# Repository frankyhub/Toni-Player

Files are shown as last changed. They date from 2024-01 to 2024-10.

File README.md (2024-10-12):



<div align="center">

|[:skull:ISSUE](https://github.com/frankyhub/Toni-Player/issues?q=is%3Aissue)|[:speech_balloon: Forum /Discussion](https://github.com/frankyhub/Toni-Player/discussions)|[:grey_question:WiKi](https://github.com/frankyhub/Toni-Player/wiki)||
|--|--|--|--|
| | | | |
||<a href="https://github.com/frankyhub/Toni-Player/issues">|<a href="https://github.com/frankyhub/Toni-Player/discussions">|<a href="https://github.com/frankyhub/Toni-Player/releases">|
|| <a href="https://github.com/frankyhub/Toni-Player/pulse" alt="Activity">| <a href="https://github.com/frankyhub/Toni-Player/graphs/traffic">  |<a href="https://github.com/frankyhub?tab=stars"> |
</div>

# Toni-Player

## Story
Dieses Projekt beschreibt einen einfach zu bedienenden MP3-Player für Kinder. Die wesentlichen Komponenten sind ein ESP32, ein RFID-Modul, ein SD-Kartenleser, ein Verstärker und ein Lautsprecher. Optional sind noch ein Akku mit Laderegler und ein Step-Up-Modul möglich. Die Grundidee des ToniPlayers besteht darin, dass Tracks einfach ausgewählt werden, indem ein RFID-getaggtes Objekt auf dem Player platziert wird, wodurch ein physischer Schlüssel zu einer Datei oder einen Ordner erstellt wird.

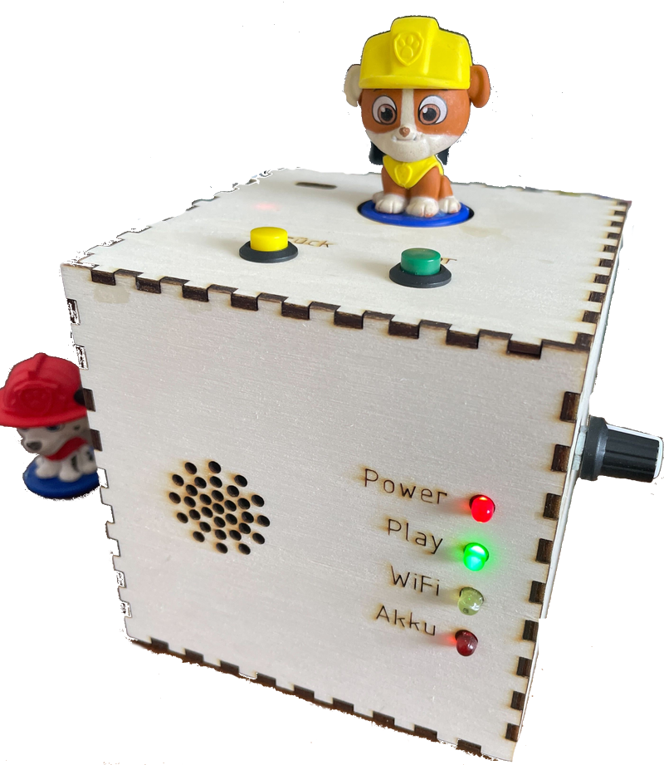
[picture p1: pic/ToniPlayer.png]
Der ToniPlayer


## Grundbedienung
Zunächst muss eine SD-Karte mit MP3-Dateien in Ordnern vorbereitet werden. Die Ordner mit MP3-Dateien können am PC kopiert oder über einen Browser nach Aktivierung des Access Point (AP) auf die SD-Karte geladen werden. Der erste RFID-Tag, der vom Lesegerät gescannt wird, wird zum "Master-Tag". Dieser startet keine Audio-Datei, sondern aktiviert die WiFi-Schnittstelle im AP-Modus, SSID "ToniPlayer", kein Passwort. Die gelbe LED leuchtet. Die nächsten gescannten RIFD-Tags werden automatisch nacheinander mit den Ordnern verknüpft, die MP3-Dateien enthalten. Die Verknüpfung zwischen RFID-Tags und Dateien wird in der Datei "tags.txt" im Stammordner der SD-Karte gespeichert. Wenn die automatische Verknüpfung nicht zu den gewünschten Ergebnissen führt, kannst du diese Datei einfach in einem Texteditor bearbeiten. Um neue Tracks auf den ToniPlayer hochzuladen, scannst du den "Master-Tag", verbindest dich in den Netzwerkeinstellungen des Handys/Tablet mit dem ToniPlayer AP und startest im Browser http://192.168.4.1 . Jetzt kannst du einen Track oder die Verzeichnis auf die SD-Karte laden. Entferne den WIFI-Tag, lege einen neuen, noch nicht zugewiesenen RFID-Tag auf den RFID-Scanner um ihn mit dem neu hochgeladenen Verzeichnis/MP3-Datei zu verknüpfen. Wird ein zugewiesener RFID-Tag auf den Kartenleser gestellt, starten die zugewiesenen MP3-Dateien und die grüne LED leuchtet. Beim Entfernen des RFID-Tag stoppt der ToniPlayer und es blinkt die grüne LED. Nach einer Minute geht der ToniPlayer in den Standby-Betrieb, alle LEDs sind dann aus. Die vor- und zurück-Taste erlauben im Play-Betrieb das skippen der MP3-Dateien. Ein kurzer Tastendruck skippt eine MP3-Datei und ein lager Tastendruck bedeutet schneller Vor- oder Rücklauf. Die Reset-Taste startet den ToniPlayer neu. Leuchtet die rote Akku-LED empfiehlt es sich den Akku zeitnah aufzuladen. Dies ist mit einem USB-Mini Kabel mit einem 5V Handy-Ladegerät oder einer 5V Power-Bank möglich. Sie zeigt auch Fehlerzustände an.

Bearbeiten der SD-Karte am PC
Kopiere deine MP3-Dateien in ein Verzeichnis. Z.B.: 01Album / 01xxx.mp3. Verzeichnisse können beliebig verschachtelt werden, aber jedes Verzeichnis sollte nur MP3-Dateien oder Unterverzeichnisse enthalten. Wenn die automatische Zuordnung von Schlüsseln zu Ordnern nicht korrekt ist, kannst du die "tags.txt" manuell bearbeiten. Du kannst ein Tag auch mit mehreren Verzeichnissen oder beliebigen Dateien verknüpfen. Der Verstärker verfügt über ein Lautstärke-Poti mit Schalter. Ist der Schalter EIN, wird der ToniPlayer mit Spannung versorgt und die POWER-LED leuchtet.

---

## Hardware
Die Hardware für den ToniPlayer:

+ ESP32 Dev Board mit Shield
+ RFID-RC522 Kartenleser
+ SD-Kartenleser (SD-Karte: 32GB 90MB/sec)
+ NF-Verstärker mit Lautsprecher
+ 3,7V Akku 18650 mit Laderegler, Akku-Case (3D-Druck)
+ Step-Up-Modul (3,7V>5V)
+ 4 LEDs, gelb, grün, 2x rot
+ 3 Taster (vor, zurück, Reset)
+ Gehäuse (Lasercutter)
+ Abstandshalter (3D-Druck)
+ Verbrauchs- und Hilfsmaterial

---

## Aufbau und Montage

Verdrahtung:

+ ESP32 > RFID-RC522
+ 3.3V -> 3.3V
+ GPIO4 -> RST
+ GND -> GND
+ N/C -> IRQ
+ GPIO19 -> MISO
+ GPIO23 -> MOSI
+ GPIO18 -> SCK
+ GPIO5 -> SDA

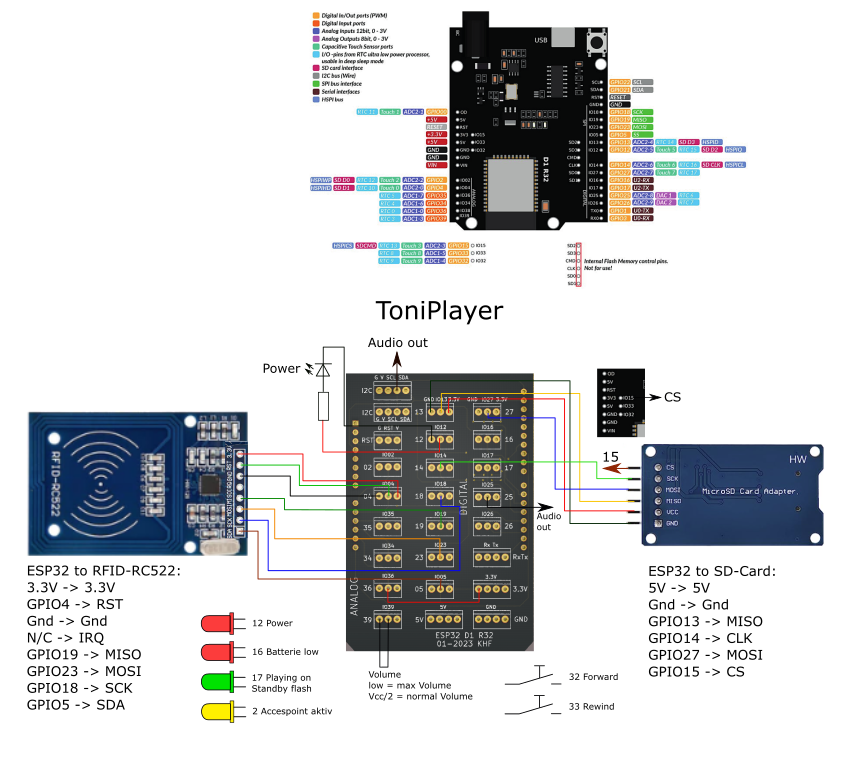
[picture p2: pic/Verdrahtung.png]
Verdrahtung


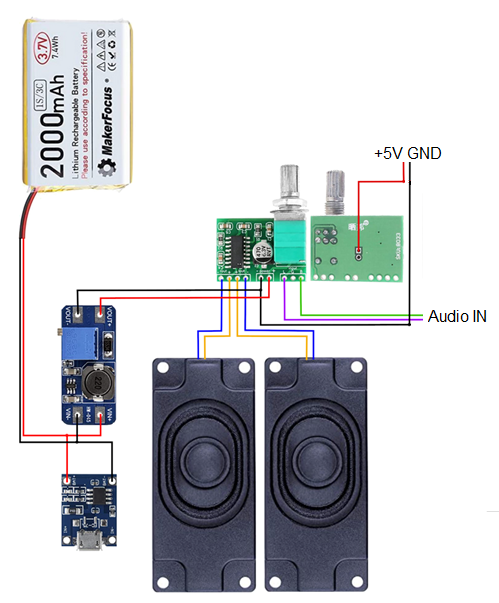
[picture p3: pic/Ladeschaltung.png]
Die Ladeschaltung


---

+ ESP32 > SD-Card
+ 5V -> 5V
+ GND -> GND
+ GPIO13 -> MISO
+ GPIO14 -> CLK
+ GPIO27 -> MOSI
+ GPIO15 -> CS

---

ESP32 > Audio

GPIO22 -> in
GND -> GND
GPIO39 -> Gnd (max volume) oder VCC/2 (normal volume)
GPIO36 -> 3.3V

---

Verstärker mit Lautsprecher

+ ESP32 > Anzeige
+ 4 Status-LEDs (gemeinsame Kathode, 1000Ohm Vorwiderstände):
+ GPIO21 -> Gelb (leuchtet, wenn WIFI aktiviert ist, blinkt bei WIFI-Aktivität)
+ GPIO17 -> Grün (leuchtet während des Spielens, blinkt im Leerlauf)
+ GPIO16 -> Rot (zeigt Fehlerzustände an und Akku laden)
+ GPIO12 -> Rot (zeigt Power an)

---

## Steuerung

Zwei Tasten
GPIO32 und GPIO33: Tasten, Verbindung zur Masse; Vorheriger / Nächster Titel (kurzes Drücken) - schnelles Vorspulen / Zurückspulen (langes Drücken)
Reset-Taste > ESP32 Reset
GPIO39 Lautstärkeregler

---

## Power

+ Akku > Step-Up-Modul und Laderegler
+ Step up Modul > Verstärker
+ GPIO36 -> Angeschlossen an die Batteriespannung zur Erfassung des Batteriezustands, Verbindung zu 3,3 V
+ GPIO12 -> High, wenn die Stromversorgung eingeschaltet ist

---

## Software

Bibliotheken:
[RFID-Bibliothek](https://github.com/miguelbalboa/rfid)
[ESP8266Audio](https://github.com/earlephilhower/ESP8266Audio) Diese Bibliothek kann viel mehr als nur MP3-Dekodierung!
[ESP8266Audio ESP8266_Spiram](https://github.com/Gianbacchio/ESP8266_Spiram)

Download:
ToniPlayer Software
Gehäuse
Gehäuse und 3D-Druck Dateien für den ToniPlayer:

Download:
3D-Druck Dateien ToniPlayer
Lasercutter Datei ToniPlayer

--- 

## Gehäuse

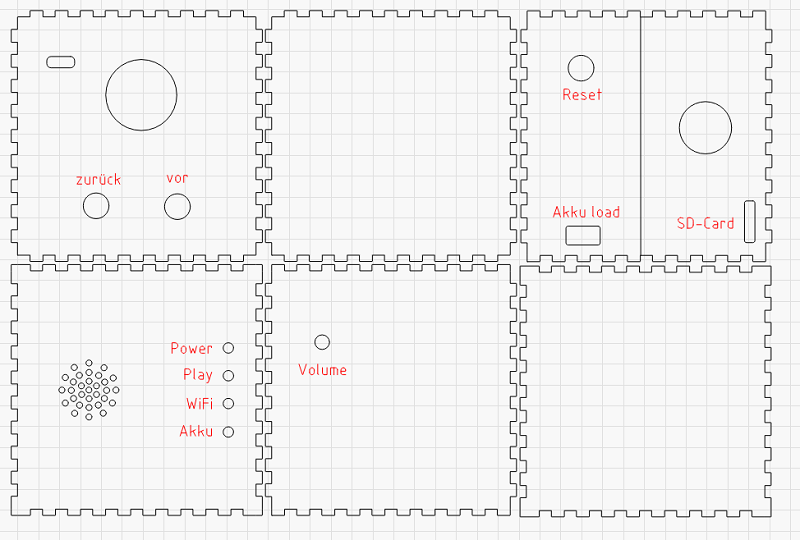
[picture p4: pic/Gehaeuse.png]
Gehäuse


---

## Inbetriebnahme

Serieller Monitor

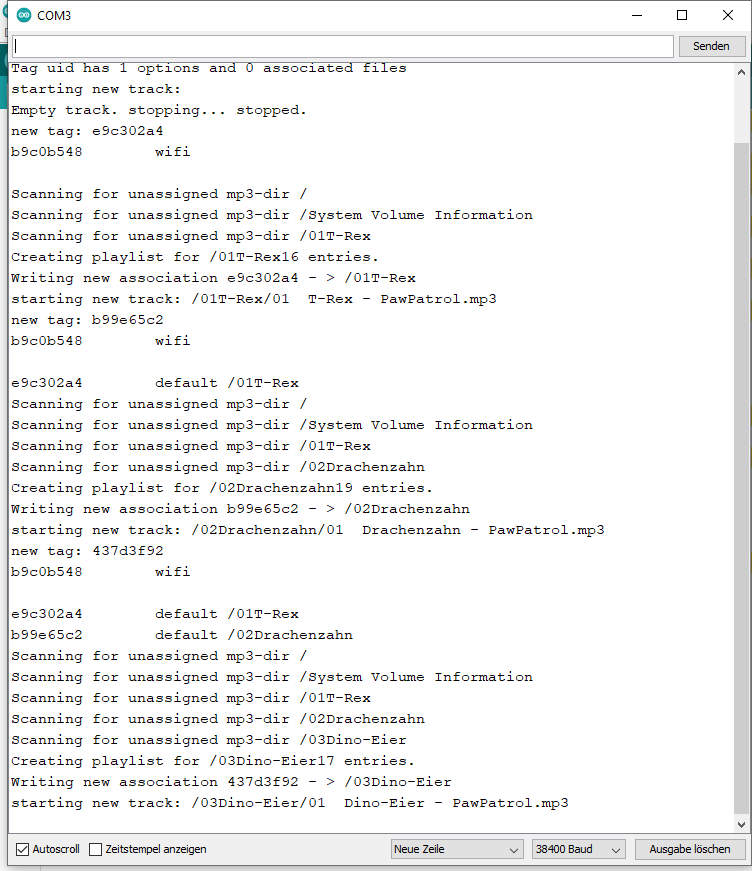
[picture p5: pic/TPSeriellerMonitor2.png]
Serieller Monitor


Access Point

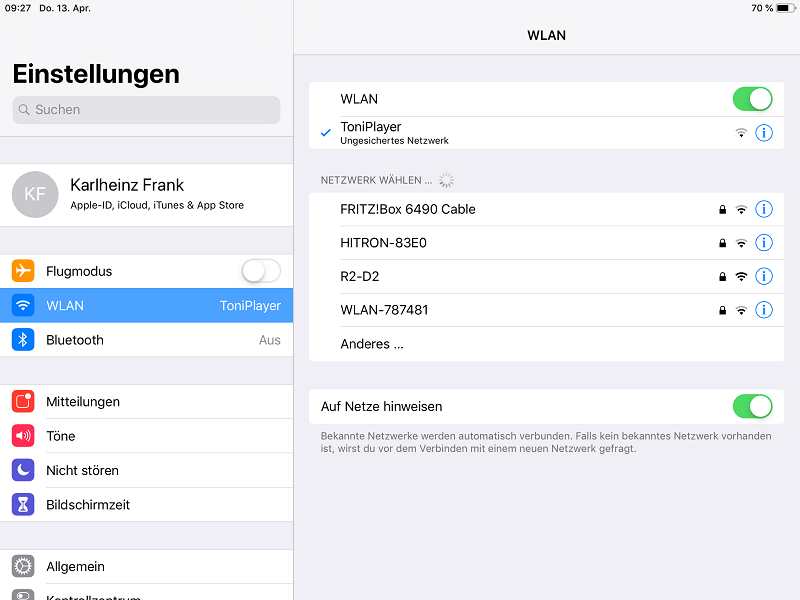
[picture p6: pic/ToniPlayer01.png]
Access Point


ToniPlayer WEB-Interface

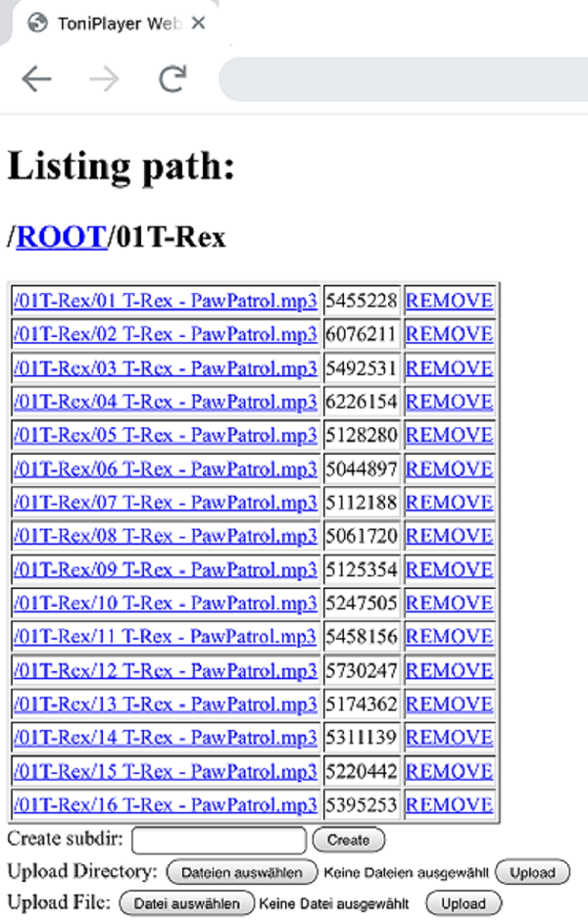
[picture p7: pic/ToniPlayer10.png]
ToniPlayer WEB-Interface1


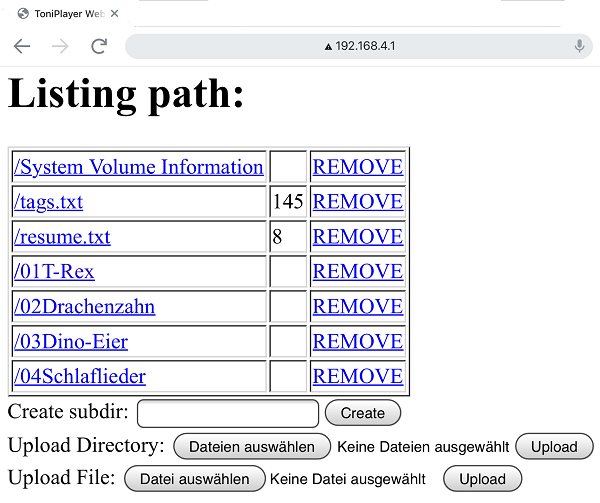
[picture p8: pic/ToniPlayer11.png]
ToniPlayer WEB-Interface2


---

<div style="position:absolute; left:2cm; ">   
<ol class="breadcrumb" style="border-top: 2px solid black;border-bottom:2px solid black; height: 45px; width: 900px;"> <p align="center"><a href="#oben">nach oben</a></p></ol>
</div>  

---

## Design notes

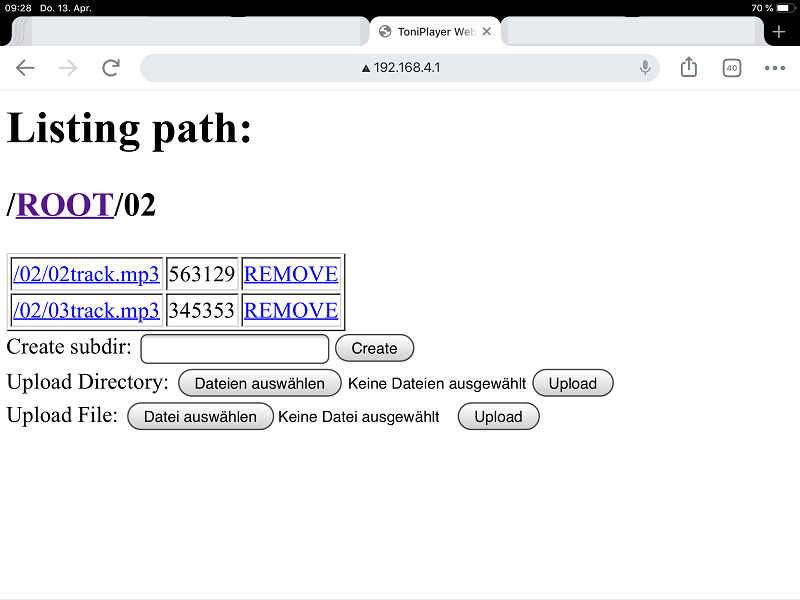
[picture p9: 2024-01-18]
pic/ToniPlayer03.png

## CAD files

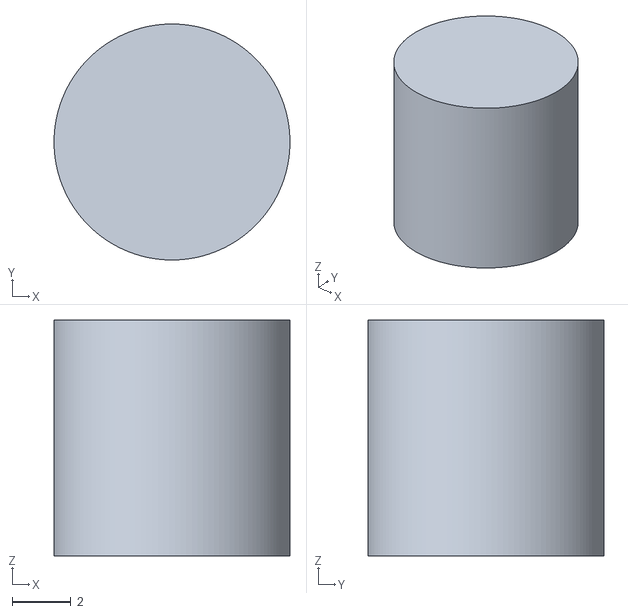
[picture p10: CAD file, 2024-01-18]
3D/PIN8mm.stl
8.00 x 8.00 x 8.00

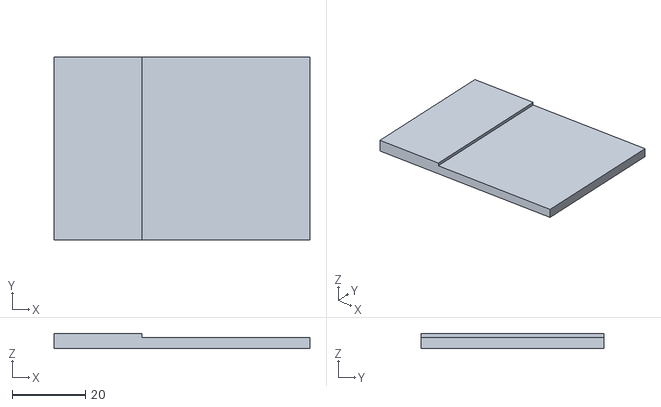
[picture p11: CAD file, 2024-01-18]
3D/RFID-Spacer.stl
70.0 x 50.0 x 4.00

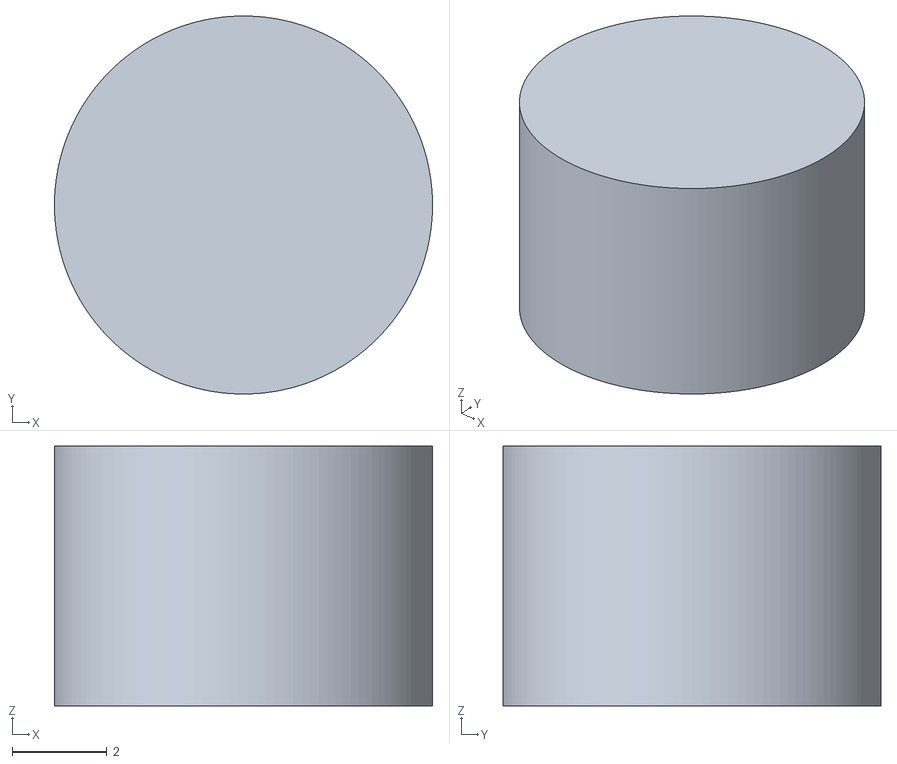
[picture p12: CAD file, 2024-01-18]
3D/PIN5-5mmSD-Card.stl
8.00 x 8.00 x 5.50

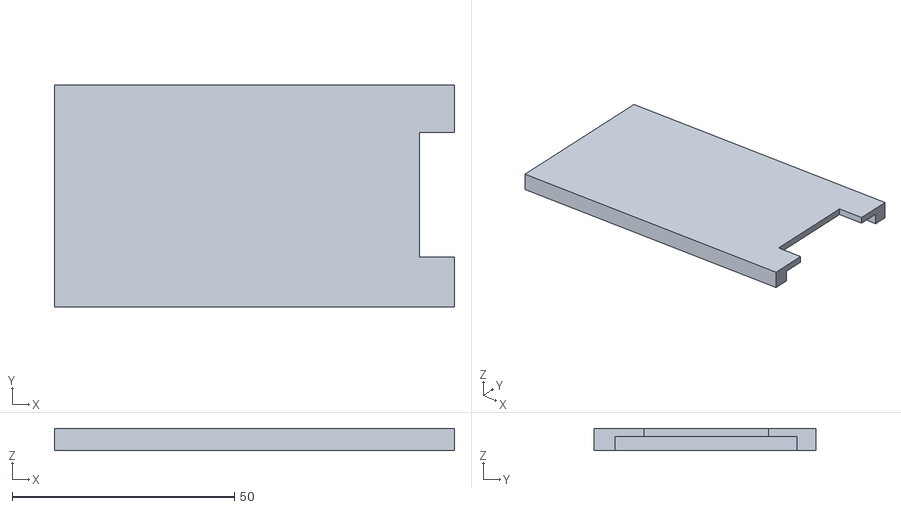
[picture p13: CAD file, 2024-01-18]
3D/RFID-SpacerV2.stl
90.0 x 50.0 x 5.00

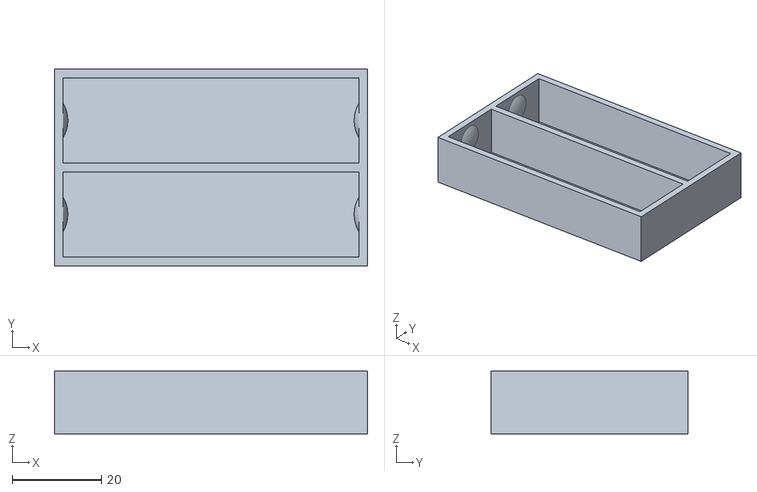
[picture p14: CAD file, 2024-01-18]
3D/Akku-Case.stl
70.0 x 44.0 x 14.0

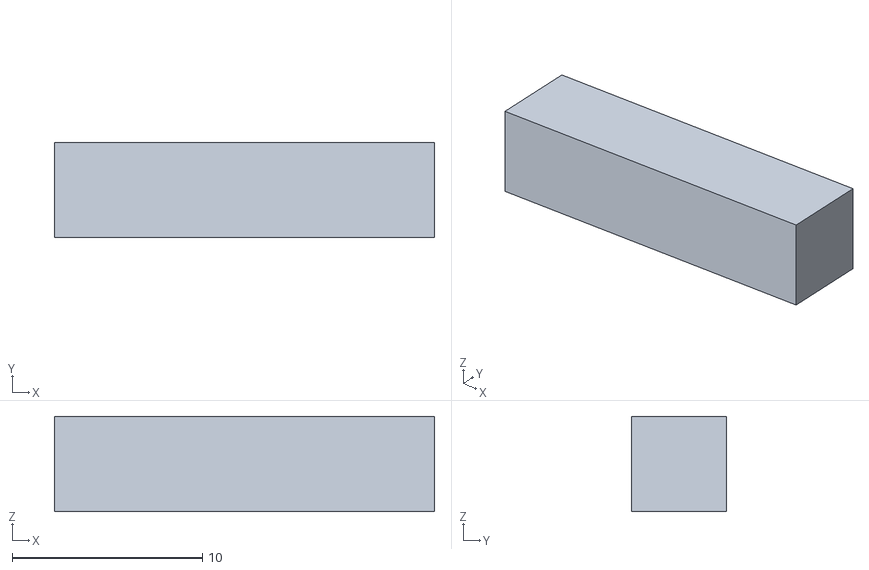
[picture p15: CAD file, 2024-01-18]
3D/Spacer_20x5x5.stl
20.0 x 5.00 x 5.00

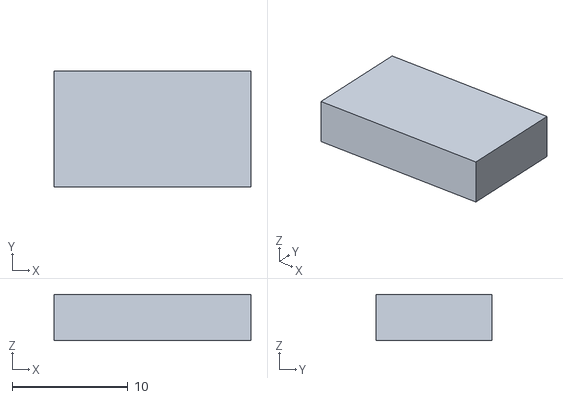
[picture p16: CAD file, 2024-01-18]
3D/Lade-Spacer.stl
17.0 x 10.0 x 4.00

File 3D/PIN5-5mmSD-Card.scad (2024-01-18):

$fn=130;

D_sock=8;    //Sockeldurchmesser

H_sock=5.5;   //Sockelhöhe


//Sockel
H=H_sock-6;
color("SlateGray")
//color("WhiteSmoke")

cylinder (h=H_sock, d=D_sock);

  

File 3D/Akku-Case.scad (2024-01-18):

/*
*******************************************
Objekt Info: Akku 18650 Box einfach/zweifach

*******************************************
Version: 30.04.2022 khf
*******************************************
*/

//***************   Auswahl   *************

        //Auswahl 1x Case oder 2x Case
        part="case2"; // case1, case2

//***************   Libraries  ************

//keine

//*****************************************

//***************  Parameter   *************
$fn=60;
//*****************************************

//**************   Programm  **************


module case1(){
//Case 1x
 union(){
difference()
translate(v = [0, 21, 0])
difference(){
cube(size = [70,23,14], center = true);
translate(v = [0, 0, 1])
cube(size = [66.1,19,15], center = true);
}


//+Pol
translate(v = [-39.5, 21, 2])
difference(){
sphere(d = 15);
rotate([0,0,90])
translate(v = [-10, -6, -10])
cube(size = [20,25,20]);
    }

// /*
//-Pol
 translate(v = [39.5, 21, 2])
 union(){
    difference(){
sphere(d = 15);
rotate([0,0,-90])
translate(v = [-10, -6, -10])
cube(size = [20,25,20]);
 }
}

}
}



module case2(){
//Case Nr 1
 union(){
difference()
translate(v = [0, 21, 0])
difference(){
cube(size = [70,23,14], center = true);
translate(v = [0, 0, 1])
cube(size = [66.1,19,15], center = true);
}


//+Pol
translate(v = [-39.5, 21, 2])
difference(){
sphere(d = 15);
rotate([0,0,90])
translate(v = [-10, -6, -10])
cube(size = [20,25,20]);
    }

// /*
//-Pol
 translate(v = [39.5, 21, 2])
 union(){
    difference(){
sphere(d = 15);
rotate([0,0,-90])
translate(v = [-10, -6, -10])
cube(size = [20,25,20]);
 }
}

}

//Case 2x

 translate(v = [0, 21, 0])
 union(){
difference()
translate(v = [0, 21, 0])
difference(){
cube(size = [70,23,14], center = true);
translate(v = [0, 0, 1])
cube(size = [66.1,19,15], center = true);
}


//+Pol
translate(v = [-39.5, 21, 2])
difference(){
sphere(d = 15);
rotate([0,0,90])
translate(v = [-10, -6, -10])
cube(size = [20,25,20]);
    }

//-Pol
 translate(v = [39.5, 21, 2])
 union(){
    difference(){
sphere(d = 15);
rotate([0,0,-90])
translate(v = [-10, -6, -10])
cube(size = [20,25,20]);
 }
}
}
}

//Part:

  if(part=="case1")
    case1();
  else if(part=="case2")
    case2();

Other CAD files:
3D/PIN8mm.scad
3D/Lade-Spacer.scad
3D/RFID-Spacer.scad
3D/RFID-SpacerV2.scad
3D/Spacer_20x5x5.scad

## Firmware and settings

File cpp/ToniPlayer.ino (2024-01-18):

/*************************************************************************************************
                                      PROGRAMMINFO
**************************************************************************************************
Funktion: Toni MP3-Player mit RFID-Kennung, SD-Card und Accses-Point WEB-Server

**************************************************************************************************
Version: 12.04.2023
**************************************************************************************************
Board: ESP32 Dec Module (ESP32vn IoT UNO) V1.0.6
**************************************************************************************************
Libraries:
https://github.com/espressif/arduino-esp32/tree/master/libraries
C:\Users\User\Documents\Arduino
D:\gittemp\Arduino II\A156_Wetterdaten_V3
**************************************************************************************************
C++ Arduino IDE V1.8.19
**************************************************************************************************
Einstellungen:
https://dl.espressif.com/dl/package_esp32_index.json
http://dan.drown.org/stm32duino/package_STM32duino_index.json
http://arduino.esp8266.com/stable/package_esp8266com_index.json
*************************************************************************************************

Wiring

ESP32 to RFID-RC522:
3.3V -> 3.3V
GPIO4 -> RST
Gnd -> Gnd
N/C -> IRQ
GPIO19 -> MISO
GPIO23 -> MOSI
GPIO18 -> SCK
GPIO5 -> SDA

ESP32 to SD-Card:
3.3V -> 3.3V
Gnd -> Gnd
GPIO13 -> MISO
GPIO14 -> CLK
GPIO27 -> MOSI
GPIO15 -> CS

ESP32 to Headphone (PDM output via I2S; alternatives available):
GPIO22 -> in
Gnd -> Gnd
Dummy (unless using additional wiring as detailed, below):
GPIO39 -> Gnd (for max volume) or VCC/2 (for normal volume)
GPIO36 -> 3.3V

Additional wiring
Controls:
GPIO39 volume control (connect to a potentiomenter from 0 to 3.3v)
GPIO32 and GPIO33: buttons, connect to ground; previous / next track (short press) - fast forward / rewind (long press)
RGB-Status LED (common kathode, add resistors as required):

GPIO2 -> Yellow (lights if WIFI enabled, blinks on WIFI activity)
GPIO17 -> Green (lights while playing, blinks while idle)
GPIO16 -> Red (indicates error states, low battery)

Power:
GPIO36 -> Connected to battery voltage for sensing battery state. Be sure to limit the voltage range, e.g. using a voltage divider. 
You may also have to adjust the margins in config.h. If you want to skip this, connect to 3.3v.
GPIO12 -> Goes high, when power should be on, goes low to shut down.
 */


#include <SPI.h>
#include <MFRC522.h>
#include <SD.h>
#include "Playlist.h"
#include "Button.h"
#include "WebInterface.h"  // optional!
#include "StatusIndicator.h"

#include "AudioFileSourceSD.h"
#include "AudioFileSourceBuffer.h"
//#include "AudioOutputBuffer.h"
#include "AudioGeneratorMP3.h"
#include "AudioOutputI2SNoDAC.h"
#include "AudioOutputI2S.h"
#include "InterruptableOutput.h"

#include "config.h"

AudioFileSourceSD *file;
AudioGeneratorMP3 *mp3;
AudioFileSourceBuffer *buff;
AudioOutput *realout;
InterruptableOutput *out;

const char resumefile[] = "/resume.txt";
void resumeSession();

SPIClass sdspi(HSPI);
File root;

MFRC522 mfrc522(MFRC522_CS_PIN, MFRC522_RST_PIN);

Button<20, 500> b_forward, b_rewind;
SemaphoreHandle_t control_mutex;
void uiloop(void *);

void setup() {
  pinMode(POWER_CONTROL_PIN, OUTPUT);
  digitalWrite(POWER_CONTROL_PIN, true);

  Serial.begin(38400);

  SPI.begin();			// Init SPI bus
  sdspi.begin(SD_SCK_PIN, SD_MISO_PIN, SD_MOSI_PIN, SD_CS_PIN); // Separate SPI bus for SD card.
  WiFi.mode(WIFI_OFF);
  btStop();

  pinMode(FORWARD_PIN, INPUT_PULLUP);
  pinMode(REWIND_PIN, INPUT_PULLUP);

  mfrc522.PCD_Init();		// Init MFRC522
  mfrc522.PCD_DumpVersionToSerial();	// Show details of PCD - MFRC522 Card Reader details

  if (!SD.begin(15, sdspi)) {
    Serial.println("SD card initialization failed!");
    indicator.setPermanentStatus(StatusIndicator::Error);
  }

  Serial.println("Hardware init complete");

  file = new AudioFileSourceSD();
  buff = new AudioFileSourceBuffer(file, 2048);

#if defined(OUTPUT_NO_DAC)
  realout = new AudioOutputI2SNoDAC(); // Output as PDM via I2S: pin 22
#elif defined(OUTPUT_INTERNAL_DAC)
  realout = new AudioOutputI2S(0, true); // Output via internal DAC: pins 25 and 26
#elif defined(OUTPUT_I2S_DAC)
  realout = new AudioOutputI2S(); // Output via external I2S DAC: pins 25, 26, and 22
#else
#error No output mode defined in config.h
#endif

  out = new InterruptableOutput(realout);
  mp3 = new AudioGeneratorMP3();

  if (SD.exists(resumefile)) {
    resumeSession();
  }

  control_mutex = xSemaphoreCreateMutex();
  // Handle controls in separate task. Esp. reading RFID tags takes too long, causes hickups in the playback, if used in the same thread.
  xTaskCreate(uiloop, "ui", 10000, NULL, 1, NULL);
}

// four bits to hex notation. Only for values between 0 and 15, obviously.
char bitsToHex (byte bits) {
  if (bits <= 9) return ('0' + bits);
  return ('a') + (bits - 10);
}

String uidToString(const MFRC522::Uid &uid) {
  String ret;
  for (int i = 0; i < uid.size; ++i) {
    ret += bitsToHex(uid.uidByte[i] >> 4);
    ret += bitsToHex(uid.uidByte[i] & 0xf);
  }
  return ret;
}

struct ControlsState {
  ControlsState() { volume = 0; navigation = None; }
  String uid;
  bool haveTag() const {
    return (uid.length() > 0);
  }
  int volume;
  enum {
    NextTrack,
    PreviousTrack,
    FastForward,
    Rewind,
    None
  } navigation;
} controls;

struct PlayerState {
  PlayerState() { finished = false; playing = false; idle_since = 0; };
  File folder;
  String uid;
  bool finished;
  bool playing;
  Playlist list;
  uint32_t idle_since;
} state;

#include <esp_wifi.h>
void doShutdown() {
  stopPlaying();
  Serial.println("Shutting down");
  if (!state.finished) {
    File f = SD.open(resumefile, FILE_WRITE);
    if (f) {
      f.println(state.uid);
      f.println(state.list.serialize());  // position in playlist
      f.println(buff->getPos());          // position in track
    }
    f.close();
  } else {
    SD.remove(resumefile);
  }
  digitalWrite(POWER_CONTROL_PIN, LOW);
  // actually, we *should* not reach any of the lines below, but possibly the power control pin is not connected, so let's try to minimize consumption, at least
  delay(1000);
  esp_wifi_stop();
  esp_deep_sleep_start();
}

// resume session after power down
void resumeSession() {
  File f = SD.open(resumefile);
  if (!f) return;
  state.uid = readLine(f);
  loadPlaylistForUid(state.uid);
  std::vector<String> positions;
  split(readLine(f), ',', &positions);
  state.list.unserialize(positions);
  startTrack(state.list.getCurrent());
  buff->seek(readLine(f).toInt(), SEEK_SET);
  stopPlaying();
}

void uiloop(void *) {
  static int tag = 0;
  // keep a temporary copy of all control values, to keep mutex locking simple
  ControlsState controls_copy;
  byte adc_count = 0;
  int adc_sum = 0;
  int adc_pin = VOL_PIN;
  uint32_t init_delay = millis();
  if (!init_delay) init_delay = 1;

  while (true) {
    if (mfrc522.PICC_IsNewCardPresent() && mfrc522.PICC_ReadCardSerial()) {
      controls_copy.uid = uidToString (mfrc522.uid);
      if (!tag) {
        Serial.print("new tag: ");
        Serial.println(controls_copy.uid);
      }
      tag = 5;
    } else {
      // It's not unusual at all for a card to "disappear" for a read or two,
      // so we assume the previous card is still present until we've seen several
      // misses in a row.
      if (--tag <= 0) {
        tag = 0;
        controls_copy.uid = String();
      }
    }

    // Analog read is terribly noisy, and changing volume too often causes audio artefacts.
    // Therefore, we average over 10 samples (the lazy way, no moving average), and then check wether the new value
    // is more than a threshold value away from the previous reading.
    if (adc_count < 10) {
      ++adc_count;
      adc_sum += analogRead(adc_pin);
    } else {
      int adc_readout = adc_sum / adc_count;
      adc_sum = 0;
      adc_count = 0;
      if (adc_pin == VOL_PIN) {
        if ((controls_copy.volume > adc_readout + VOL_THRESHOLD) || (controls_copy.volume < adc_readout - VOL_THRESHOLD)) {
          Serial.println(adc_readout);
          controls_copy.volume = adc_readout;
        }
        adc_pin = BAT_SENSE_PIN;
      } else {
//        Serial.println(adc_readout);
        if (adc_readout <= BAT_WARN_THRESHOLD) {
          indicator.setPermanentStatus(StatusIndicator::BatteryLow);
          if (adc_readout < BAT_CUTOUT_THRESHOLD) {
            doShutdown();
          }
        } else if (adc_readout >= BAT_WARN_RELEASE) {
          indicator.setPermanentStatus(StatusIndicator::BatteryLow, false);
        }
        adc_pin = VOL_PIN;
      }
    }

    if (!init_delay) {
      // Read button states
      b_forward.update(!digitalRead(FORWARD_PIN));
      b_rewind.update(!digitalRead(REWIND_PIN));
    } else {
      // skip reading button states for a brief time, intially. A button may have been pressed to turn on the device.
      if (millis() - init_delay > 2000) init_delay = 0;
    }

    xSemaphoreTake(control_mutex, portMAX_DELAY);
    // Much easier to handle clicks with mutex locked
    controls_copy.navigation = controls.navigation;
    if (b_forward.wasClicked()) controls_copy.navigation = ControlsState::NextTrack;
    else if (b_forward.isHeld()) controls_copy.navigation = ControlsState::FastForward;
    else if (b_rewind.wasClicked()) controls_copy.navigation = ControlsState::PreviousTrack;
    else if (b_rewind.isHeld()) controls_copy.navigation = ControlsState::Rewind;

    controls = controls_copy;
    xSemaphoreGive(control_mutex);

    indicator.update();
    vTaskDelay (10);
  }
}

void stopPlaying() {
  out->stop();
  state.playing = false;
  indicator.setPermanentStatus(StatusIndicator::Playing, false);
  if (!isWebInterfaceActive()) state.idle_since = millis();
}

void startTrack(String track) {
  Serial.print("starting new track: ");
  Serial.println(track);

  state.idle_since = 0;
  if (mp3->isRunning()) mp3->stop();
  if (track.length() && file->open(track.c_str())) {
    buff->seek(0, SEEK_SET);
    mp3->begin(buff, out);
    state.finished = false;
  } else {
    Serial.print("Empty track. stopping...");
    stopPlaying();
    state.finished = true;
    indicator.setTransientStatus(StatusIndicator::AtFileEOF);
    Serial.println(" stopped.");
  }
}

String readLine(File &f) {
  String line;
  if (!f) return line;
  while (f.available()) {
    char c = f.read();
    if (c == '\n') return line;
    if (c != '\r') line += c;
  }
  return line;
}

const char* TAGS_FILE = "/tags.txt";

File findNextUnassignedMP3Folder(const std::vector<String> &known_directories, File dir=SD.open("/")) {
  Serial.print("Scanning for unassigned mp3-dir ");
  Serial.println(dir.name());

  // If this folder is already assigned, it might still have unassigned sub-folders
  bool assigned = false;
  for (int i = known_directories.size() - 1; i >= 0; --i) {
    if (known_directories[i] == dir.name()) {
      assigned = true;
      break;
    }
  }

  File entry = dir.openNextFile();
  while (entry) {
    if (entry.isDirectory()) {
      File candidate = findNextUnassignedMP3Folder(known_directories, entry);
      if (candidate) return candidate;
    } else {
      if (assigned) {
        entry = dir.openNextFile();
        continue;
      }

      String n(entry.name());
      n.toLowerCase();
      if (n.endsWith(".mp3")) {
        return (dir);
      }
    }
    entry = dir.openNextFile();
  }
  return File();
}

void split(String in, char sep, std::vector<String> *out) {
  while(in.length()) {
    int next = in.indexOf(sep);
    if (next >= 0) {
      out->push_back(in.substring(0, next));
      in = in.substring(next+1);
    } else {
      out->push_back(in);
      break;
    }
  }
}

// tags.txt file format:
// UID\t[FLAG1[;FLAG2[;FLAG3...]]]\tDIR1[;DIR2[;DIR3...]]
void parseConfigLine(const String &line, std::vector<String> *options, std::vector<String> *files) {
  int tab1 = line.indexOf('\t');
  if (tab1 < 0) return;
  int tab2 = line.indexOf('\t', tab1 + 1);
  String config = line.substring(tab1+1, tab2);
  split(config, ';', options);

  // now parse files
  if (tab2 < 0) return;
  String dirspec = line.substring(tab2+1);
  split(dirspec, ';', files);
}

void loadPlaylistForUid(String uid) {
  File tagmap = SD.open(TAGS_FILE);
  // If there is no tags-file (yet), assign the current uid to be the "master control" tag, i.e. the one
  // to enable wifi.
  if (!tagmap) {
    tagmap = SD.open(TAGS_FILE, FILE_WRITE);
    tagmap.print(uid.c_str());
    tagmap.println("\twifi\t");
    tagmap.close();
    tagmap = SD.open(TAGS_FILE);
  }

  // Look for a stored mapping of this tag to options / playlist
  std::vector<String> known_directories;
  while(tagmap && tagmap.available()) {
    String line = readLine(tagmap);
    Serial.println(line);
    std::vector<String> files, options;
    parseConfigLine(line, &options, &files);
    known_directories.insert(known_directories.end(), files.begin(), files.end());

    if (line.startsWith(uid)) {
      Serial.print("Tag uid has ");
      Serial.print(options.size());
      Serial.print(" options and ");
      Serial.print(files.size());
      Serial.println(" associated files");
      state.list = Playlist(files);
      for (unsigned int i = 0; i < options.size(); ++i) {
        if (options[i] == "wifi") state.list.wifi_enabled = true;
      }
      return;
    }
  }
  tagmap.close();

  // if there is no stored mapping for this uid, yet, try to associate it with a folder that has not yet been assigned
  File f = findNextUnassignedMP3Folder(known_directories);
  state.list = Playlist(f);

  // and store the new association
  if (!f) return;
  Serial.print("Writing new association ");
  Serial.print(uid);
  Serial.print(" - > ");
  Serial.println(f.name());
  File newmap = SD.open(TAGS_FILE, FILE_WRITE);
  newmap.seek(newmap.size());  // Contrary to documentation, FILE_WRITE does not seem to imply APPEND?!
  newmap.print(uid.c_str());
  newmap.print("\tdefault\t");
  newmap.println(f.name());
  newmap.close();
}

void startOrResumePlaying() {
  if (controls.uid == state.uid) {  // resume previous
  } else {  // new tag
    loadPlaylistForUid(controls.uid);
    startTrack(state.list.next());
    state.uid = controls.uid;
  }

  if (state.list.wifi_enabled) {
    startWebInterface(true);
  }

  if (!state.finished) {
    out->begin();
    state.playing = true;
    indicator.setPermanentStatus(StatusIndicator::Playing);
  }
}

void seek(int dir) {
  // We're spending quite some time in this function, and don't need to check controls, so release the mutex
  xSemaphoreGive(control_mutex);

  int timeconst = out->getRate() / 10;

  // First, fade out the volume to avoid noise.
  // While doing so, measure input consumption as a crude estimate for how far to seek.
  uint32_t opos = buff->getPos();
  out->fadeOut(timeconst);
  while (out->isSpecialModeActive() && mp3->isRunning()) mp3->loop();
  int32_t npos = buff->getPos();
  int32_t delta = (npos - opos) * 32;
  if (delta < 50) delta = buff->getSize() / 50;  // Fallback, if delta seems off
  npos += delta * dir;
  if (dir < 0) npos -= (timeconst*4 + 1152); // For rewind, substract the total size that we are playing forward during seek
  if (npos < 0) {
    indicator.setTransientStatus(StatusIndicator::AtFileEOF);
    npos = 0;
  }
  if (npos >= buff->getSize()) {
    indicator.setTransientStatus(StatusIndicator::AtFileEOF);
    npos = buff->getSize() - 1;
  }
  buff->seek(npos, SEEK_SET);

  // Insert a brief silence to avoid noise while the mp3-stream seeks to the next frame
  out->setSwallow(1152);   // NOTE: The *typical* mp3 frame length is 1152
  while (out->isSpecialModeActive() && mp3->isRunning()) mp3->loop();

  // Fade in, again
  out->fadeIn(timeconst);
  while (out->isSpecialModeActive() && mp3->isRunning()) mp3->loop();

  // Now play a brief sample a regular speed, a) For auditive feedback, b) as a defined rate-limit for the seeking
  out->setTimeout(timeconst*2);   // Play a brief sample at regular volume and speed for auditive feedback
  while (out->isSpecialModeActive() && mp3->isRunning()) mp3->loop();

  xSemaphoreTake(control_mutex, portMAX_DELAY);
}

void loop() {
  static int vol = controls.volume;
  xSemaphoreTake(control_mutex, portMAX_DELAY);
  if (controls.haveTag()) {
    if (vol != controls.volume) {
      vol = controls.volume;
      realout->SetGain(3.0 - (controls.volume / (4096.0 / 3)));
    }
    if (!state.playing) {
      startOrResumePlaying();
    } else {
      if (controls.navigation == ControlsState::None) {
        if (!mp3->isRunning() || !mp3->loop()) {
          indicator.setTransientStatus(StatusIndicator::AtFileEOF);
          startTrack(state.list.next());
        }
      } else {
        if (controls.navigation == ControlsState::NextTrack) {
          startTrack(state.list.next());
        } else if (controls.navigation == ControlsState::PreviousTrack) {
          String prev = state.list.previous();
          if (prev.length() < 1) prev = state.list.next();  // no previous track: re-start first
          startTrack(prev);
        } else if (controls.navigation == ControlsState::FastForward) {
          seek(1);
        } else {
          seek(-1);
        }
        controls.navigation = ControlsState::None;  // signal to ui thread that we have seen the button
      }
    }
  } else {
    if (state.playing) {
      stopPlaying();
    }
    if (state.finished) {
      state.uid = "";  // Card was finished, so clear resume state, when it is removed. That way, if card is removed, readded, playing will start over.
      state.finished = false;
    }
    stopWebInterface();
  }
  xSemaphoreGive(control_mutex);
  if (!state.playing && !isWebInterfaceActive()) {
    if (state.idle_since) {
      if ((millis() - state.idle_since) > (IDLE_SHUTDOWN_TIMEOUT * 1000UL)) {
        doShutdown();
      }
    }
  }
}

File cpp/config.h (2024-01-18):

/*
config.h
 */

// This file is for your local config: PIN assignements, output mode, WIFI credentials, etc.
// Make changes here as you want. However, if you plan on contributing anything
// back to this project (i.e. submit a PR), you should
// git update-index --assume-unchanged config.h
// so your local config does not get uploaded.

#ifndef CONFIG_H
#define CONFIG_H

// Uncomment exactly one of the following:
#define OUTPUT_NO_DAC   // For easy headphone-connectable mono-output via pin 22
//#define OUTPUT_INTERNAL_DAC  // Output via internal DAC: pins 25 and 26 - Stereo, but high impedance and not-so great resolution, esp. at low volume
//#define OUTPUT_I2S_DAC  // Output via external I2S DAC: pins 25, 26, and 22 - Best quality, but needs additional circuitry.

// pin mapping
// RFID reader. NOTE: The MFRC522 reader uses the default VSPI pins in addition to these!
#define MFRC522_RST_PIN         4
#define MFRC522_CS_PIN          5

// SD card. This needs to be on a separate SPI bus, as transactions with the RFID reader take too long for decent playback.
// Could be remapped to other pins, and in fact, these are not - quite - the standard pins. I had trouble uploading new code, while using the default pins
#define SD_SCK_PIN             14
#define SD_MISO_PIN            13
#define SD_MOSI_PIN            27
#define SD_CS_PIN              15

#define VOL_PIN                39  // Volume control. 0...3.3v
#define VOL_THRESHOLD          60  // Volume control change sensitivity
#define FORWARD_PIN            32  // Forward button. INPUT_PULLUP, i.e. button should connect to ground
#define REWIND_PIN             33  // REWIND button. INPUT_PULLUP, i.e. button should connect to ground

// Status indicator
#define LED_BLUE_PIN           2
#define LED_GREEN_PIN          17
#define LED_RED_PIN            16

// Power management
#define BAT_SENSE_PIN          36
#define POWER_CONTROL_PIN      12
#define BAT_WARN_THRESHOLD   ((int) (4096 * (3.15 / 2) / 3.3)) // You may want to determine the best value, empirically, but the idea is that the bat sense pin is connected to
                                                               // the battery voltage (after power control mosfet) via a 50/50 voltage divider. Then the warning will trigger around 3.4 (3.15 in my circuit)
                                                               // volts divided by 2.
#define BAT_WARN_RELEASE     (BAT_WARN_THRESHOLD + 100)  // Release value for battery low warning. A little higher than the warning threshold to avoid flicker
#define BAT_CUTOUT_THRESHOLD ((int) (4096 * (2.95 / 2) / 3.3))  // See above for details. Cut out around 3.1 (2.95 in my circuit) volts to protect the battery.

#define IDLE_SHUTDOWN_TIMEOUT 120  // Cut the power after this many seconds of being idle (no card present, or finished playing)

#endif
